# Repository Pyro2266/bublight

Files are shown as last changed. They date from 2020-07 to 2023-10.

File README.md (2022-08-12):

# BubLight
Light up your hookah with a Raspberry and a neopixel ring!

Get your **RaspberryPi**, connect the **neopixel LED ring** and the **BMP180 pressure sensor** to it, configure it, upload and start **BubLight** `.jar` file and you are ready to go!
You can then connect to a **BubLight** web UI, where you can **configure colors** and **light modes** and see a **nice graph** showing **realtime pressure**!

## NOTE
This **hobby project** is still a **WORK IN PROGRESS**.
However, it had some successful demos :).

## Build and start in simulated mode
Hardware parts (the LED ring and the pressure sensor) are simulated in the simulated mode.

Steps:
1. Clone and build BubLight repository. Go to the directory where you want to clone BubLight and execute:
    ```
    git clone https://github.com/Pyro2266/bublight.git
    cd bublight
    mvn clean install -P build-web
    ```

2. Go to the backend target directory: `cd bublight-backend/target`

3. Start `.jar` file in a simulated mode with command: `java -jar bublight-backend-0.0.2-SNAPSHOT.jar --bublight.simulatedPressure=true --bublight.simulatedLed=true`.

4. WebUI and REST endpoints are now available on `localhost` at port `8080`.

5. Go to the WebUI (`localhost:8080`) and click things or play with Postman collection from the `docs` directory. Additionally, Swagger UI is available on URL `http://localhost:8080/swagger-ui/index.html`.

6. Enjoy! But keep in mind that everything is still under development and all the risk is on you :).

7. Feel free to leave feedback, create a PR, or an issue if something is not working.

## Connection schema
Components used in demo:
- Raspberry Zero W 1.1
- GY-68 (BMP180)
- Adafruit Neopixel Ring (16x LED)

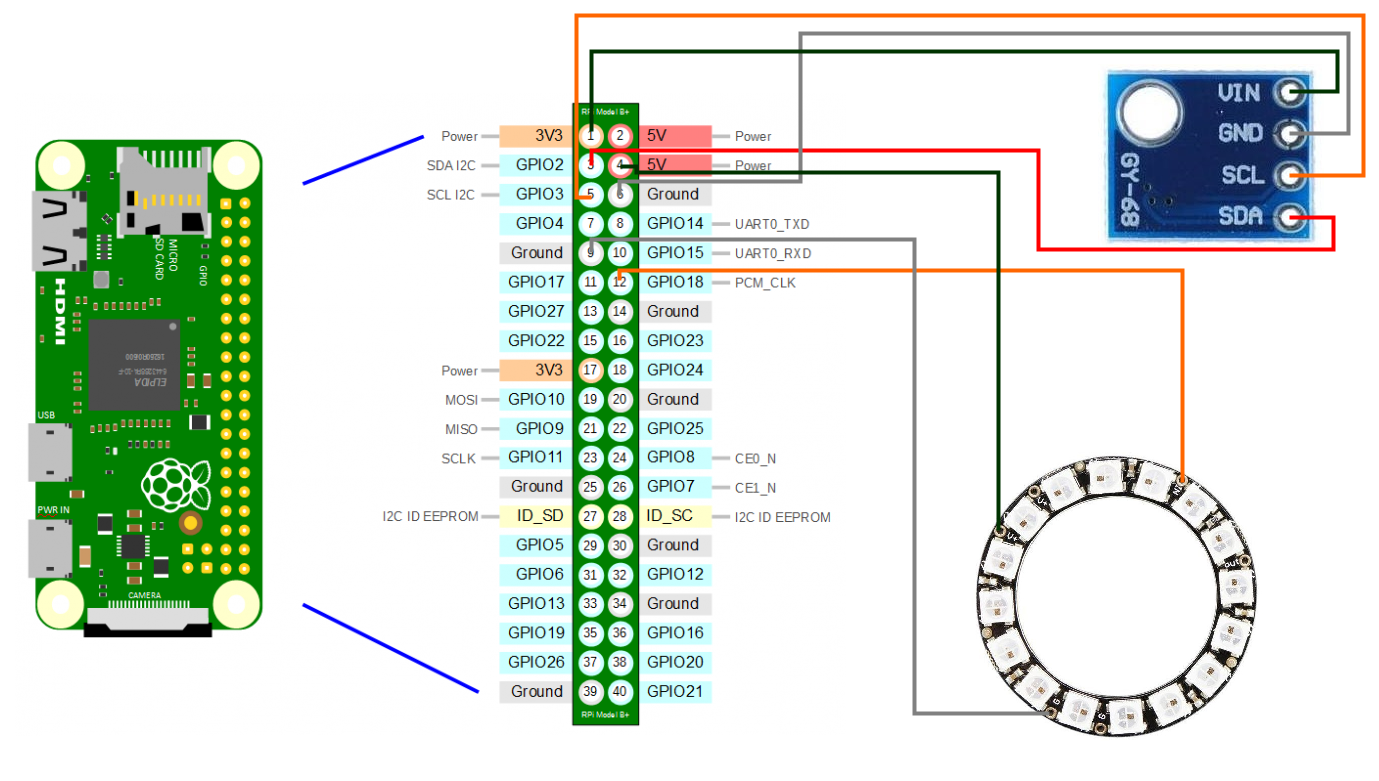
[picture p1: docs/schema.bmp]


## Build and start on Raspberry from scratch
1. Download and install [Raspberry Pi Imager](https://www.raspberrypi.org/software/)

2. Choose Raspberry Pi OS LITE and write it to the SD card (I'm using `Raspbian GNU/Linux 10 (buster)`).

3. To automatically connect to your Wi-Fi network (original guide [here](https://core-electronics.com.au/tutorials/raspberry-pi-zerow-headless-wifi-setup.html)) go to the SD card (`boot` partition) and create file `wpa_supplicant.conf` in the root directory.

4. Open `wpa_supplicant.conf` file and write there configuration of your Wi-Fi (including `country`):
    ```
    country=SK
    ctrl_interface=DIR=/var/run/wpa_supplicant GROUP=netdev
    update_config=1
    network={
    	ssid="MyWiFiNetwork"
    	psk="aVeryStrongPassword"
    	key_mgmt=WPA-PSK
    }
    ```

5. (Optional) It is possible to include multiple networks. For example I'm using Wi-Fi network I have at home and hotspot from my phone. Just include another `network` block under the first one:
    ```
    network={
    	ssid="MyWiFiNetwork1"
    	psk="aVeryStrongPassword"
    	key_mgmt=WPA-PSK
    }
   
    network={
    	ssid="MyWiFiNetwork2"
    	psk="aVeryStrongPassword"
    	key_mgmt=WPA-PSK
    }
    ```

6. Enable SSH by creating empty file called `ssh` (without and file extension) in the SD card (the same place as Wi-Fi was configured).

7. Insert SD card into your Raspberry, power it up, wait a few seconds. Now find the IP address of your Raspberry in the network (I'm using android app called [Fing](https://play.google.com/store/apps/details?id=com.overlook.android.fing)).

8. With the address obtained in previous step you can connect via SSH to the Raspberry. Default credentials are username: `pi` and password: `raspberry`. Example `ssh` command: `ssh pi@192.168.1.123`.

9. With the SSH connectiou up update and install following tools: `i2c-tools`, `wiringpi`, `swig`, `java 8` (unfortunately `java 11` does not work with Raspberry Zero):
    ```
    sudo apt-get update
    sudo apt-get install i2c-tools wiringpi swig openjdk-8-jre
    ```

10. Check if `java 8` is installed: `java -version`. You should see `openjdk version "1.8.0_212"`.

11. To enable `I2C` (original [guide](https://learn.adafruit.com/adafruits-raspberry-pi-lesson-4-gpio-setup/configuring-i2c)) and setup locale:
    1. Execute command `sudo raspi-config`.
    2. Go to `Interface Options`.
    3. Go to `I2C` and enable it.
    4. Go into `Localisation Options` and setup locale.

12. Check if `I2C` is ready with command: `sudo i2cdetect -y 1`. It should return:
    ```
         0  1  2  3  4  5  6  7  8  9  a  b  c  d  e  f
    00:          -- -- -- -- -- -- -- -- -- -- -- -- -- 
    10: -- -- -- -- -- -- -- -- -- -- -- -- -- -- -- -- 
    20: -- -- -- -- -- -- -- -- -- -- -- -- -- -- -- -- 
    30: -- -- -- -- -- -- -- -- -- -- -- -- -- -- -- -- 
    40: -- -- -- -- -- -- -- -- -- -- -- -- -- -- -- -- 
    50: -- -- -- -- -- -- -- -- -- -- -- -- -- -- -- -- 
    60: -- -- -- -- -- -- -- -- -- -- -- -- -- -- -- -- 
    70: -- -- -- -- -- -- -- 77
    ```

13. Check if locale are correct with command: `locale`.

14. Create `~/bublight` directory with command: `mkdir ~/bublight`. We will copy the application here.

15. Clone and build BubLight repository on your local computer (preferably in another console while keeping the SSH connection to the RPi open). Go to the directory where you want to clone BubLight and execute:
    ```
    git clone https://github.com/Pyro2266/bublight.git
    cd bublight
    mvn clean install -P build-web
    ```

16. Copy executable `jar` file (from `bublight-backend/target` directory) and application properties (from `bublight-backend/src/main/resources` directory) to the Raspberry (into the `~/bublight` directory). Don't forget to update your IP address.
   ```
   scp bublight-backend/target/bublight-backend-0.0.2-SNAPSHOT.jar pi@IP_OF_YOUR_RPI:~/bublight
   scp bublight-backend/src/main/resources/application.properties pi@IP_OF_YOUR_RPI:~/bublight
   ```

17. Go back to the SSH session to Raspberry and go to the `bublight` directory we created before: `cd ~/bublight`.

18. Check application properties if everything is set up correctly (if simulated mode is turned off and number of LEDs is correct): `nano application.properties`.

19. Start BubLight with command: `sudo java -jar bublight-backend-0.0.2-SNAPSHOT.jar`. It takes a minute or two to start the application.

20. WebUI and REST endpoints are now available at port `8080`.

21. Go to the WebUI (`IP_OF_YOUR_RPI:8080`) and click things or play with Postman collection from the `docs` directory. Additionally, Swagger UI is available on URL `http://IP_OF_YOUR_RPI:8080/swagger-ui/index.html`.

22. Enjoy! But keep in mind that everything is still under development and all the risk is on you :).

23. Feel free to leave feedback, create a PR, or an issue if something is not working.

## Screenshot
To give an idea how does it look now (keep in mind that it's still under development).
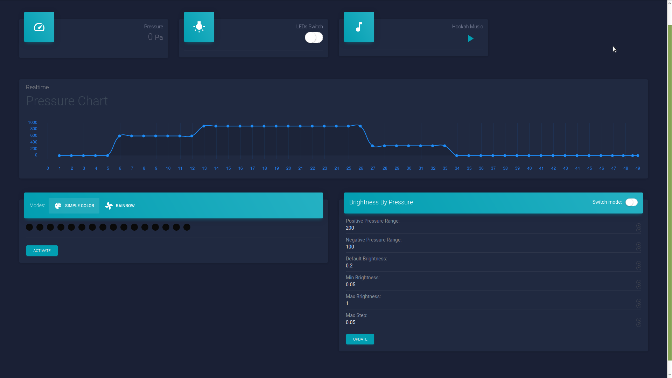
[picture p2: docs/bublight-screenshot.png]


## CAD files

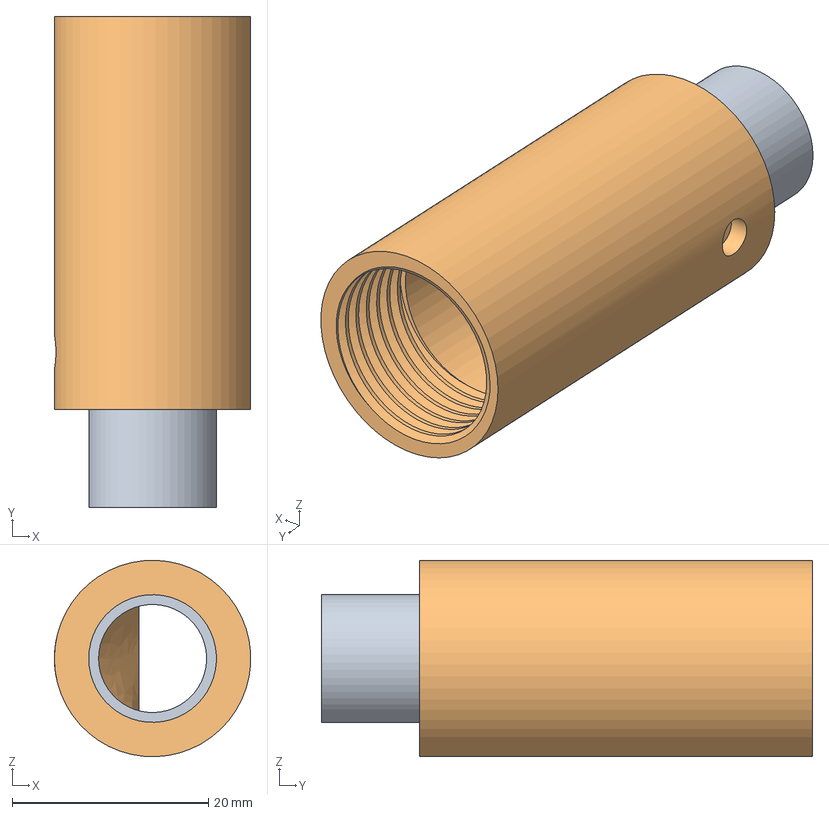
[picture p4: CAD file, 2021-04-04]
3Dmodels/Naustok.step
20.0 x 50.0 x 20.0 mm

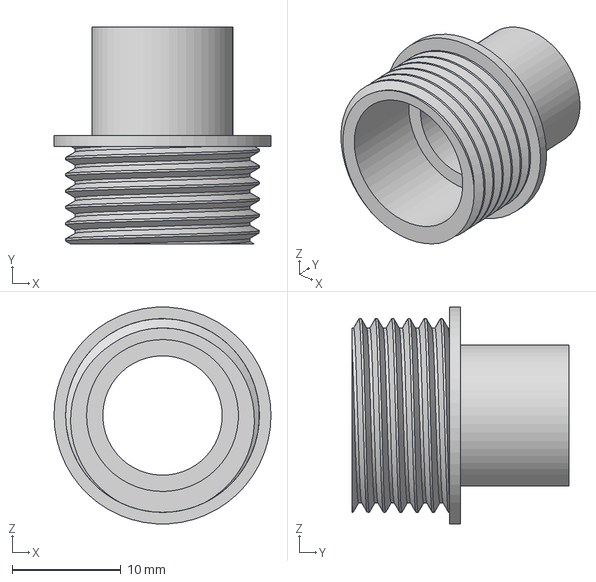
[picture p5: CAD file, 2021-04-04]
3Dmodels/Naustok_vrch.step
20.0 x 20.0 x 20.0 mm

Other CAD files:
3Dmodels/Naustok.f3z
3Dmodels/Naustok_vrch.f3d

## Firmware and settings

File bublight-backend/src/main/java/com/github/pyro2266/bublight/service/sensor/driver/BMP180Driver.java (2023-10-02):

package com.github.pyro2266.bublight.service.sensor.driver;

import com.pi4j.io.i2c.I2CBus;
import com.pi4j.io.i2c.I2CDevice;
import com.pi4j.io.i2c.I2CFactory;
import java.io.IOException;
import org.slf4j.Logger;
import org.slf4j.LoggerFactory;

/**
 * BMP-180 I2C
 * 3.3V Bosch temperature and barometric pressure sensor
 */
public class BMP180Driver implements Sensor {

    private static final Logger LOG = LoggerFactory.getLogger(BMP180Driver.class);

    private final static int BIG_ENDIAN = 1;
    private final static int BMP180_ENDIANNESS = BIG_ENDIAN;

    /*
    Prompt> sudo i2cdetect -y 1
         0  1  2  3  4  5  6  7  8  9  a  b  c  d  e  f
    00:          -- -- -- -- -- -- -- -- -- -- -- -- --
    10: -- -- -- -- -- -- -- -- -- -- -- -- -- -- -- --
    20: -- -- -- -- -- -- -- -- -- -- -- -- -- -- -- --
    30: -- -- -- -- -- -- -- -- -- -- -- -- -- -- -- --
    40: -- -- -- -- -- -- -- -- -- -- -- -- -- -- -- --
    50: -- -- -- -- -- -- -- -- -- -- -- -- -- -- -- --
    60: -- -- -- -- -- -- -- -- -- -- -- -- -- -- -- --
    70: -- -- -- -- -- -- -- 77
     */

    // This next addresses is returned by "sudo i2cdetect -y 1", see above.
    private final static int BMP180_ADDRESS = 0x77;

    // Operating Modes
    private final int BMP180_ULTRALOWPOWER = 0;
    private final int BMP180_STANDARD = 1;
    private final int BMP180_HIGHRES = 2;
    private final int BMP180_ULTRAHIGHRES = 3;

    // BMP180 Registers
    private final int BMP180_CAL_AC1 = 0xAA;  // R   Calibration data (16 bits)
    private final int BMP180_CAL_AC2 = 0xAC;  // R   Calibration data (16 bits)
    private final int BMP180_CAL_AC3 = 0xAE;  // R   Calibration data (16 bits)
    private final int BMP180_CAL_AC4 = 0xB0;  // R   Calibration data (16 bits)
    private final int BMP180_CAL_AC5 = 0xB2;  // R   Calibration data (16 bits)
    private final int BMP180_CAL_AC6 = 0xB4;  // R   Calibration data (16 bits)
    private final int BMP180_CAL_B1 = 0xB6;  // R   Calibration data (16 bits)
    private final int BMP180_CAL_B2 = 0xB8;  // R   Calibration data (16 bits)
    private final int BMP180_CAL_MB = 0xBA;  // R   Calibration data (16 bits)
    private final int BMP180_CAL_MC = 0xBC;  // R   Calibration data (16 bits)
    private final int BMP180_CAL_MD = 0xBE;  // R   Calibration data (16 bits)

    private final int BMP180_CONTROL = 0xF4;
    private final int BMP180_TEMPDATA = 0xF6;
    private final int BMP180_PRESSUREDATA = 0xF6;
    private final int BMP180_READTEMPCMD = 0x2E;
    private final int BMP180_READPRESSURECMD = 0x34;

    private int cal_AC1 = 0;
    private int cal_AC2 = 0;
    private int cal_AC3 = 0;
    private int cal_AC4 = 0;
    private int cal_AC5 = 0;
    private int cal_AC6 = 0;
    private int cal_B1 = 0;
    private int cal_B2 = 0;
    private int cal_MB = 0;
    private int cal_MC = 0;
    private int cal_MD = 0;

    private I2CDevice bmp180;
    private int mode = BMP180_STANDARD;
    private int standardSeaLevelPressure = 101325;

    public BMP180Driver() {
        this(BMP180_ADDRESS);
    }

    public BMP180Driver(int address) {
        try {
            // Get i2c bus
            LOG.debug("Connecting to bus...");
            I2CBus bus = I2CFactory.getInstance(I2CBus.BUS_1); // Depends on the RasPI version
            LOG.debug("Connected to bus. OK.");

            // Get device itself
            LOG.debug("Connecting to device...");
            bmp180 = bus.getDevice(address);
            LOG.debug("Connected to device. OK.");

            this.readCalibrationData();
        } catch (IOException | I2CFactory.UnsupportedBusNumberException e) {
            LOG.error("Exception thrown!", e);
        }
    }

    private int readU8(int reg) {
        // "Read an unsigned byte from the I2C device"
        int result = 0;
        try {
            result = this.bmp180.read(reg);
            LOG.trace("I2C: Device " + BMP180_ADDRESS + " returned " + result + " from reg " + reg);
        } catch (IOException e) {
            LOG.error("Exception thrown!", e);
        }
        return result;
    }

    private int readS8(int reg) {
        // "Reads a signed byte from the I2C device"
        int result = 0;
        try {
            result = this.bmp180.read(reg);
            if (result > 127)
                result -= 256;
            LOG.trace("I2C: Device " + BMP180_ADDRESS + " returned " + result + " from reg " + reg);
        } catch (IOException e) {
            LOG.error("Exception thrown!", e);
        }
        return result;
    }

    private int readU16(int register) {
        int hi = this.readU8(register);
        int lo = this.readU8(register + 1);
        return (BMP180_ENDIANNESS == BIG_ENDIAN) ? (hi << 8) + lo : (lo << 8) + hi; // Big Endian
    }

    private int readS16(int register) {
        int hi = 0, lo = 0;
        if (BMP180_ENDIANNESS == BIG_ENDIAN) {
            hi = this.readS8(register);
            lo = this.readU8(register + 1);
        } else {
            lo = this.readS8(register);
            hi = this.readU8(register + 1);
        }
        return (hi << 8) + lo;
    }

    public synchronized void readCalibrationData() {
        // Reads the calibration data from the IC
        cal_AC1 = readS16(BMP180_CAL_AC1);   // INT16
        cal_AC2 = readS16(BMP180_CAL_AC2);   // INT16
        cal_AC3 = readS16(BMP180_CAL_AC3);   // INT16
        cal_AC4 = readU16(BMP180_CAL_AC4);   // UINT16
        cal_AC5 = readU16(BMP180_CAL_AC5);   // UINT16
        cal_AC6 = readU16(BMP180_CAL_AC6);   // UINT16
        cal_B1 = readS16(BMP180_CAL_B1);    // INT16
        cal_B2 = readS16(BMP180_CAL_B2);    // INT16
        cal_MB = readS16(BMP180_CAL_MB);    // INT16
        cal_MC = readS16(BMP180_CAL_MC);    // INT16
        cal_MD = readS16(BMP180_CAL_MD);    // INT16

        showCalibrationData();
    }

    private void showCalibrationData() {
        // Displays the calibration values for debugging purposes
        LOG.debug("Calibration data:");
        LOG.debug("AC1 = {}", cal_AC1);
        LOG.debug("AC2 = {}", cal_AC2);
        LOG.debug("AC3 = {}", cal_AC3);
        LOG.debug("AC4 = {}", cal_AC4);
        LOG.debug("AC5 = {}", cal_AC5);
        LOG.debug("AC6 = {}", cal_AC6);
        LOG.debug("B1  = {}", cal_B1);
        LOG.debug("B2  = {}", cal_B2);
        LOG.debug("MB  = {}", cal_MB);
        LOG.debug("MC  = {}", cal_MC);
        LOG.debug("MD  = {}", cal_MD);
    }

    private int readRawTemp() throws IOException, InterruptedException {
        // Reads the raw (uncompensated) temperature from the sensor
        bmp180.write(BMP180_CONTROL, (byte) BMP180_READTEMPCMD);
        Thread.sleep(5);  // Wait 5ms
        int raw = readU16(BMP180_TEMPDATA);
        LOG.trace("Raw Temp: " + (raw & 0xFFFF) + ", " + raw);
        return raw;
    }
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

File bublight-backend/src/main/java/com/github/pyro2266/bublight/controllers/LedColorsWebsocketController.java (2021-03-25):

package com.github.pyro2266.bublight.controllers;

import com.github.pyro2266.bublight.websocket.LedColorsWebsocketService;
import com.github.pyro2266.bublight.websocket.PressureWebsocketService;
import org.slf4j.Logger;
import org.slf4j.LoggerFactory;
import org.springframework.beans.factory.annotation.Autowired;
import org.springframework.http.ResponseEntity;
import org.springframework.web.bind.annotation.*;

@RestController
@CrossOrigin(origins = "*")
@RequestMapping(path = "/ledcolor/websocket")
public class LedColorsWebsocketController {

    private static final Logger LOG = LoggerFactory.getLogger(LedColorsWebsocketController.class);

    private final LedColorsWebsocketService ledColordWebsocketService;

    @Autowired
    public LedColorsWebsocketController(LedColorsWebsocketService ledColordWebsocketService) {
        this.ledColordWebsocketService = ledColordWebsocketService;
    }

    @PostMapping(path = "/setRefreshRate/{rate}")
    public ResponseEntity setRefreshRate(@PathVariable int rate) {
        LOG.info("Request to change refresh rate of led color websocket to {} received", rate);
        ledColordWebsocketService.changeRefreshRate(rate);
        return ResponseEntity.ok().build();
    }

}

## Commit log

2018-05-16 Service and controller for setting LED via REST
2018-05-17 First PoC of changing LED intensity by difference in pressure
2018-05-21 WIP: led modes
2018-05-29 Fixed merge fail and added controller for mode switching
2019-09-15 Added skeleton and configuration for simulated LED and pressure drivers
2019-09-15 Add simulated pressure controller
2019-10-16 Return correct value in simulated pressure sensor
2019-10-19 Add websocket package | Fix simlation pressure input
2019-10-20 Build webapp and include it in spring boot fat-jar via maven plugins
2019-10-20 Prepare websocket notifier when pressure difference changes
2019-10-20 Implement websocket notifier when pressure difference changes
2019-10-22 Fix graph refresh | add overlay mode enable switch
2019-10-23 Rework pressure difference websocket notifier
2019-10-23 Create Led panel | color changes | form inputs
2019-10-23 Fix error when activating simple color mode - annotate constructor
    [BMP180Driver.java]
2019-10-23 Synchronise pressure driver
2020-07-01 Change endpoint to set simulated pressure
2021-03-16 Fix brightness by pressure request
2021-03-17 Bump springboot and pi4j versions
2021-03-19 Refactor pressure service and websockets
2021-03-19 Add websocket for current colors
2021-03-21 Remove pressure caching
2021-03-22 Add led info panel
2021-03-23 Change layout of led info panel
2021-03-23 Simple color: set all leds at once
2021-03-24 fixed problem when loop was faster after each start
    calling start multiple times caused loop to be faster because every time start was called new thread was created
    -moved thread creation into its own method
    -added check if loop is already running
    -some code format
2021-03-25 added possibility to change colors refresh rate
    refactored websocketServices to remove duplicate code
    created controller for led color frequency change
2021-04-04 Added 3D models
    [Naustok.f3z, Naustok.step, Naustok_vrch.f3d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]
2021-04-28 added endpoint for current config, made some changes to directories and packages
2022-07-23 Set log level of logging pressure to trace
2022-07-23 Set log level of logging pressure back to debug and update config
2022-07-23 Add brightness by pressure documentation
2022-08-10 Implement pressure threshold in BrightnessByPressureMode
2022-08-12 Split simulated mode to pressure and/or led simulated mode
2023-10-02 Added support for temperature
    Including controller and service and simulated controller
